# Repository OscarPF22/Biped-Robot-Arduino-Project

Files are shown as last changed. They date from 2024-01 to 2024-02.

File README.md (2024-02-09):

# Biped-Robot-Arduino-Project
This repository contains all the main files involved in the development of the Final degree project in Electronic Systems Engineering from the University of Malaga.
- PCB_ESP32_UnaCara_Galgas: This folder contains all the files from the KiCad project (PCI/PCB development).
- STL Biped Robot: This folder contains all the STL files of the 3D printed parts used to build the robot.
- analog_pid_IMU_esp32_v2: This folder contains the Arduino codes for the stability control (the analog part is commented and not used).
- ik_v14_esp32: This folder contains the Arduino codes for making the robot walk (mainly inverse kinematics).

<p align="center">
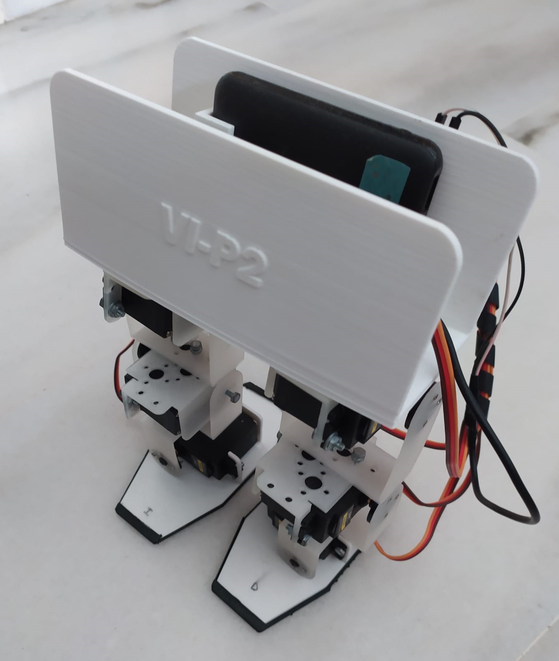
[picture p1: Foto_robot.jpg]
hoto of the final prototype
  
</p>

Walking demo video:

<p align="center">
  <a href="https://www.youtube.com/watch?v=WyaLR0LmY2Y">
    Video de ejemplo
  </a>
</p>

Stabilization demo video:

<p align="center">
  <a href="https://www.youtube.com/watch?v=4yBQPxzZWLo">
    Video de ejemplo
  </a>
</p>

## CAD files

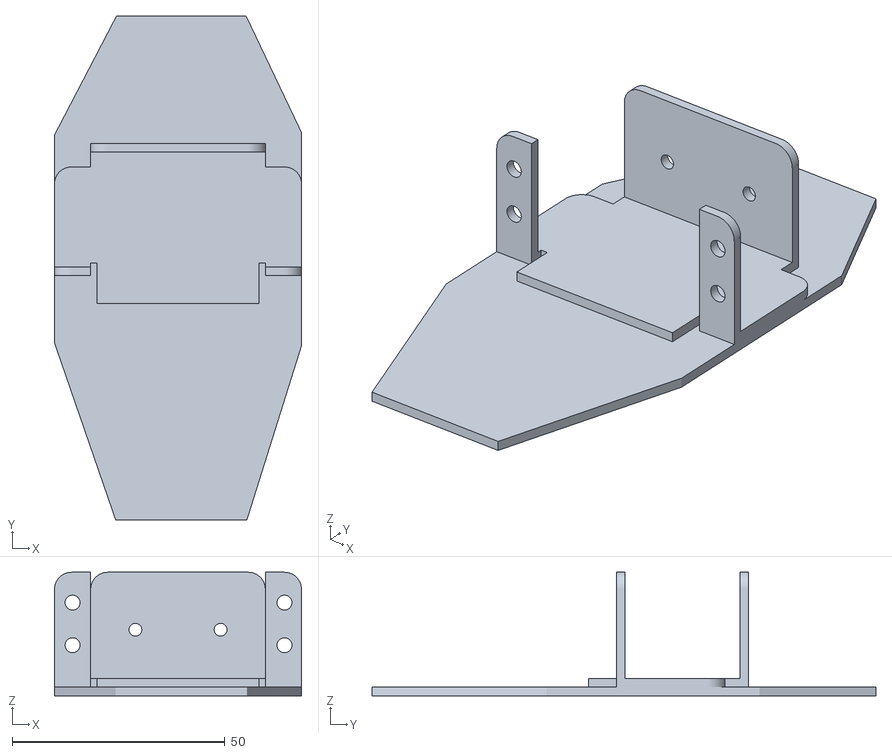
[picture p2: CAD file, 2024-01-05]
STL Biped Robot/mod_pie.stl
58.0 x 118.3 x 29.0

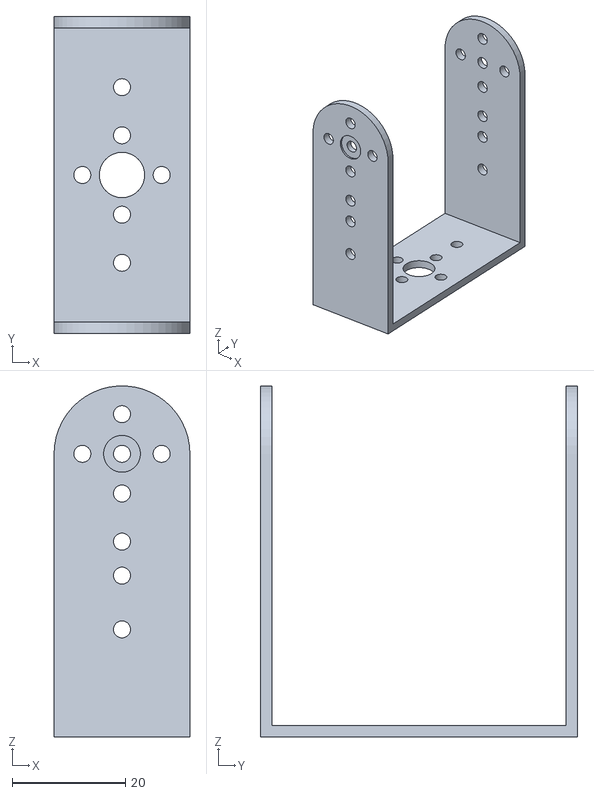
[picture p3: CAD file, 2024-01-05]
STL Biped Robot/Bracket-Long-C.stl
24.0 x 56.0 x 62.0

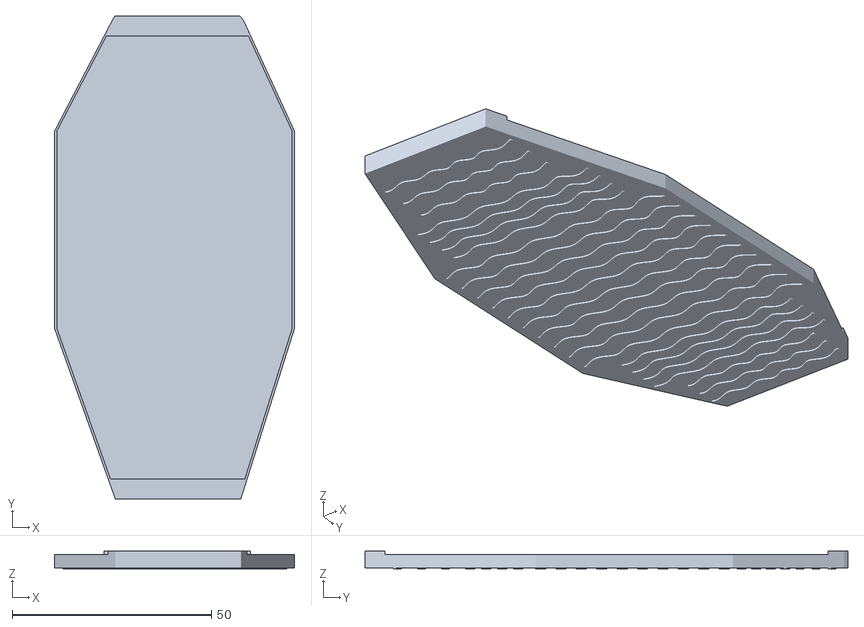
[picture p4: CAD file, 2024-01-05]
STL Biped Robot/Suela_pie_v6.stl
60.2 x 121.1 x 4.50

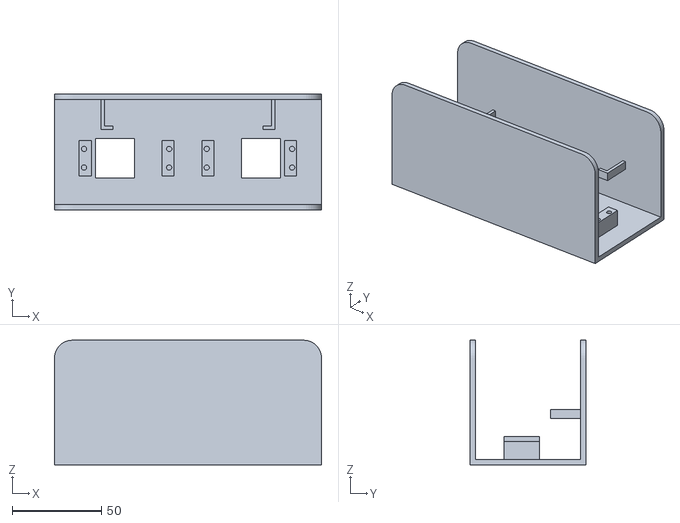
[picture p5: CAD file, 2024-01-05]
STL Biped Robot/cadera_diseño_fin.stl
150.0 x 65.0 x 70.0

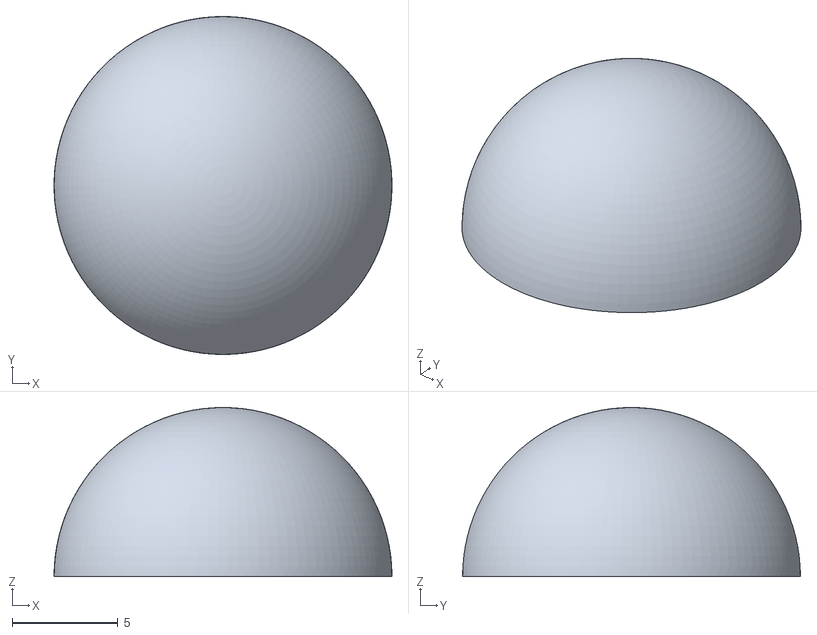
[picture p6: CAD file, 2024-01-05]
STL Biped Robot/semiesfera v1.stl
16.0 x 16.0 x 8.00

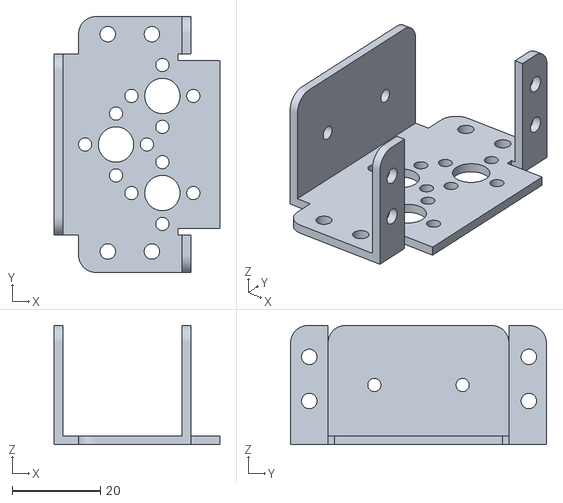
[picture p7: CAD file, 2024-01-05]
STL Biped Robot/Bracket-Multi.stl
37.5 x 58.0 x 27.0

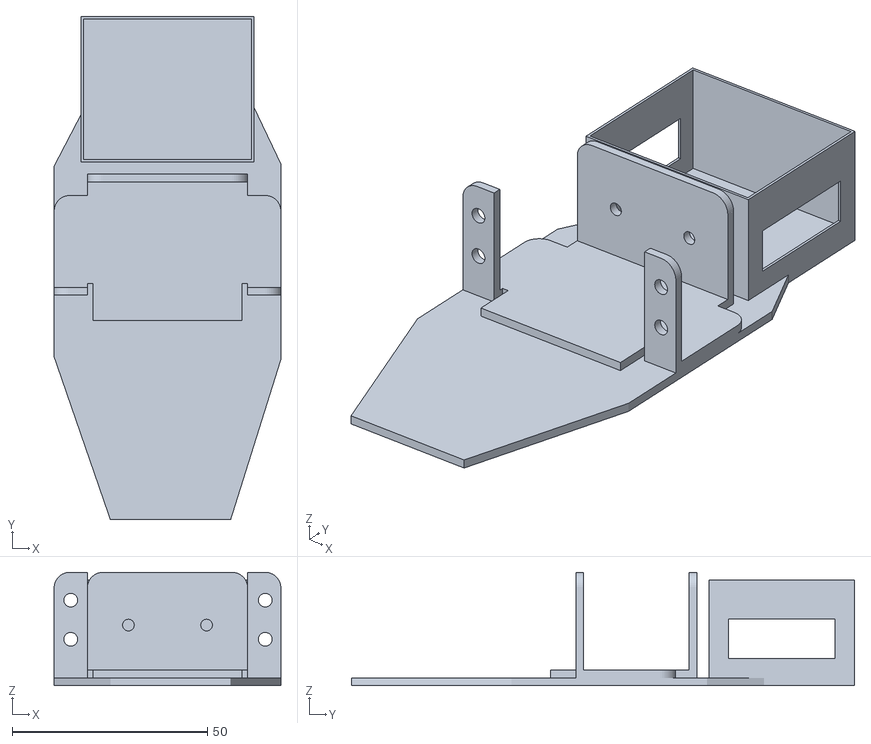
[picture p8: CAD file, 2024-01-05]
STL Biped Robot/mod_pie_placa_v2.stl
58.0 x 128.7 x 29.0

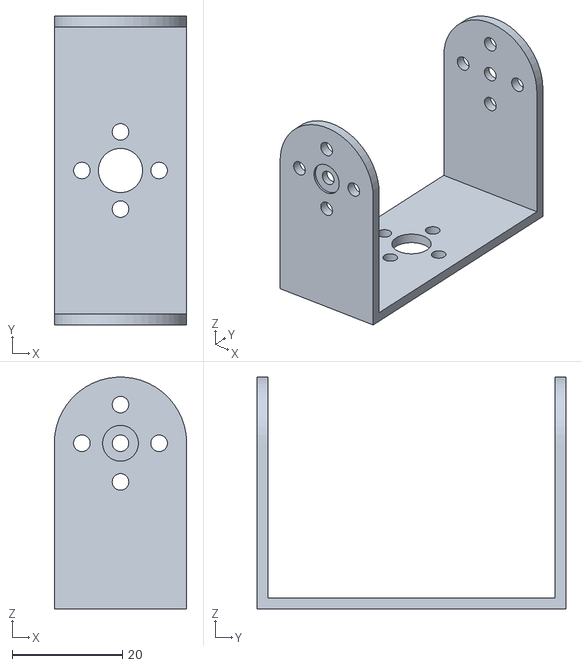
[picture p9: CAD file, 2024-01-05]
STL Biped Robot/Bracket-Reg-C.stl
24.0 x 56.0 x 42.0

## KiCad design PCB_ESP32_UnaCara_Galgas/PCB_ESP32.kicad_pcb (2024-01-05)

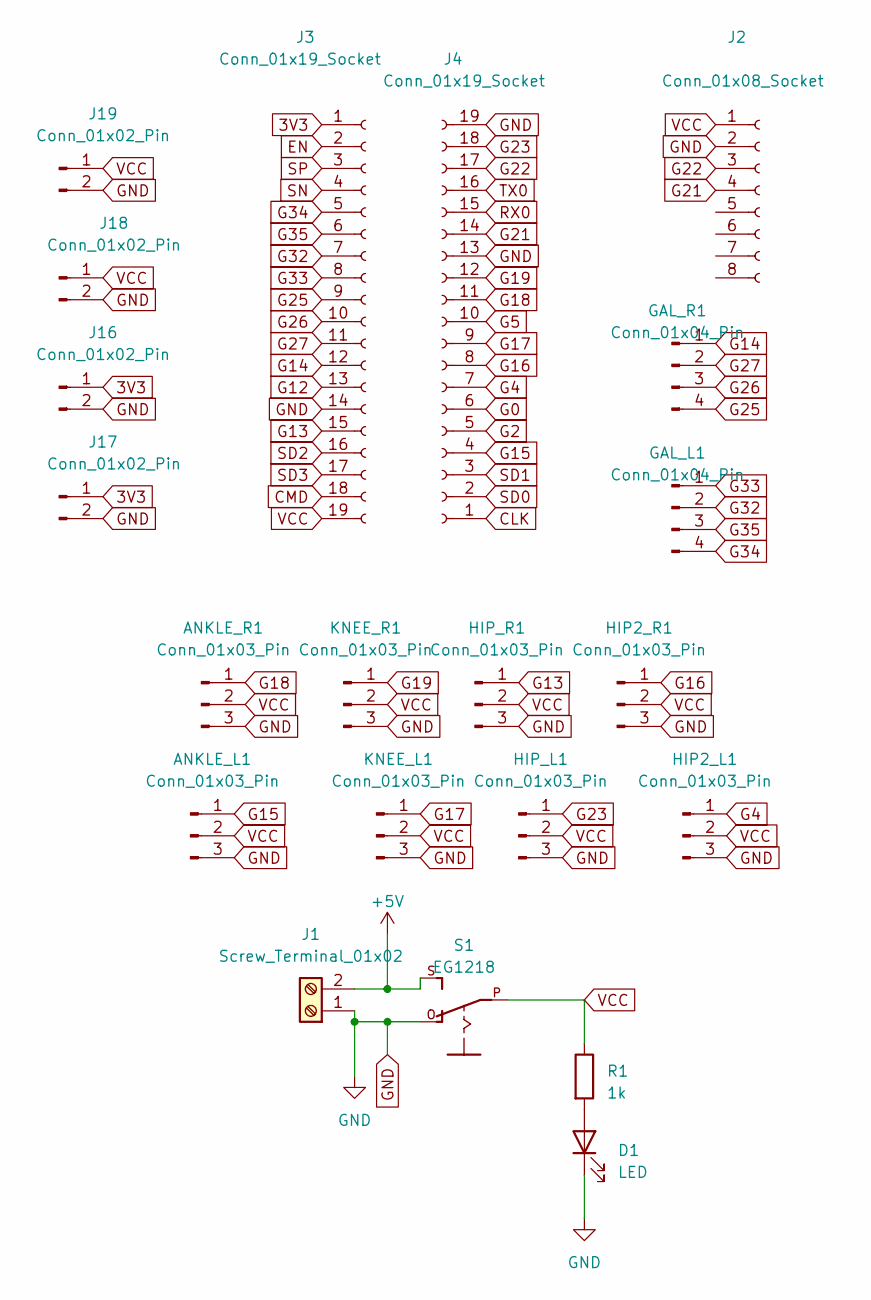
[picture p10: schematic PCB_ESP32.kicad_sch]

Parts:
ANKLE_L1: Conn_01x03_Pin; PinHeader_1x03_P2.54mm_Vertical
ANKLE_R1: Conn_01x03_Pin; PinHeader_1x03_P2.54mm_Vertical
D1: LED; LED_D3.0mm
GAL_L1: Conn_01x04_Pin; PinHeader_1x04_P2.54mm_Vertical
GAL_R1: Conn_01x04_Pin; PinHeader_1x04_P2.54mm_Vertical
HIP2_L1, HIP2_R1: Conn_01x03_Pin; PinHeader_1x03_P2.54mm_Vertical
HIP_L1: Conn_01x03_Pin; PinHeader_1x03_P2.54mm_Vertical
HIP_R1: Conn_01x03_Pin; PinHeader_1x03_P2.54mm_Vertical
J1: Screw_Terminal_01x02; TerminalBlock_Altech_AK300-2_P5.00mm
J2: Conn_01x08_Socket; PinSocket_1x08_P2.54mm_Vertical
J3, J4: Conn_01x19_Socket; PinSocket_1x19_P2.54mm_Vertical
J16, J17, J18, J19: Conn_01x02_Pin; PinHeader_1x02_P2.54mm_Vertical
KNEE_L1: Conn_01x03_Pin; PinHeader_1x03_P2.54mm_Vertical
KNEE_R1: Conn_01x03_Pin; PinHeader_1x03_P2.54mm_Vertical
R1: 1k; R_Axial_DIN0204_L3.6mm_D1.6mm_P5.08mm_Horizontal
S1: EG1218

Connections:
3V3: J3.1, J16.1, J17.1
+5V: J1.2, S1.S
CLK: J4.1
CMD: J3.18
EN: J3.2
G0: J4.6
G2: J4.5
G4: HIP2_L1.1, J4.7
G5: J4.10
G12: J3.13
G13: HIP_R1.1, J3.15
G14: GAL_R1.1, J3.12
G15: ANKLE_L1.1, J4.4
G16: HIP2_R1.1, J4.8
G17: J4.9, KNEE_L1.1
G18: ANKLE_R1.1, J4.11
G19: J4.12, KNEE_R1.1
G21: J2.4, J4.14
G22: J2.3, J4.17
G23: HIP_L1.1, J4.18
G25: GAL_R1.4, J3.9
G26: GAL_R1.3, J3.10
G27: GAL_R1.2, J3.11
G32: GAL_L1.2, J3.7
G33: GAL_L1.1, J3.8
G34: GAL_L1.4, J3.5
G35: GAL_L1.3, J3.6
GND: ANKLE_L1.3, ANKLE_R1.3, D1.1 (K), HIP2_L1.3, HIP2_R1.3, HIP_L1.3, HIP_R1.3, J1.1, J2.2, J3.14, J4.13, J4.19, J16.2, J17.2, J18.2, J19.2, KNEE_L1.3, KNEE_R1.3, S1.O
unnamed: D1.2 (A), R1.2
RX0: J4.15
SD0: J4.2
SD1: J4.3
SD2: J3.16
SD3: J3.17
SN: J3.4
SP: J3.3
TX0: J4.16
VCC: ANKLE_L1.2, ANKLE_R1.2, HIP2_L1.2, HIP2_R1.2, HIP_L1.2, HIP_R1.2, J2.1, J3.19, J18.1, J19.1, KNEE_L1.2, KNEE_R1.2, R1.1, S1.P

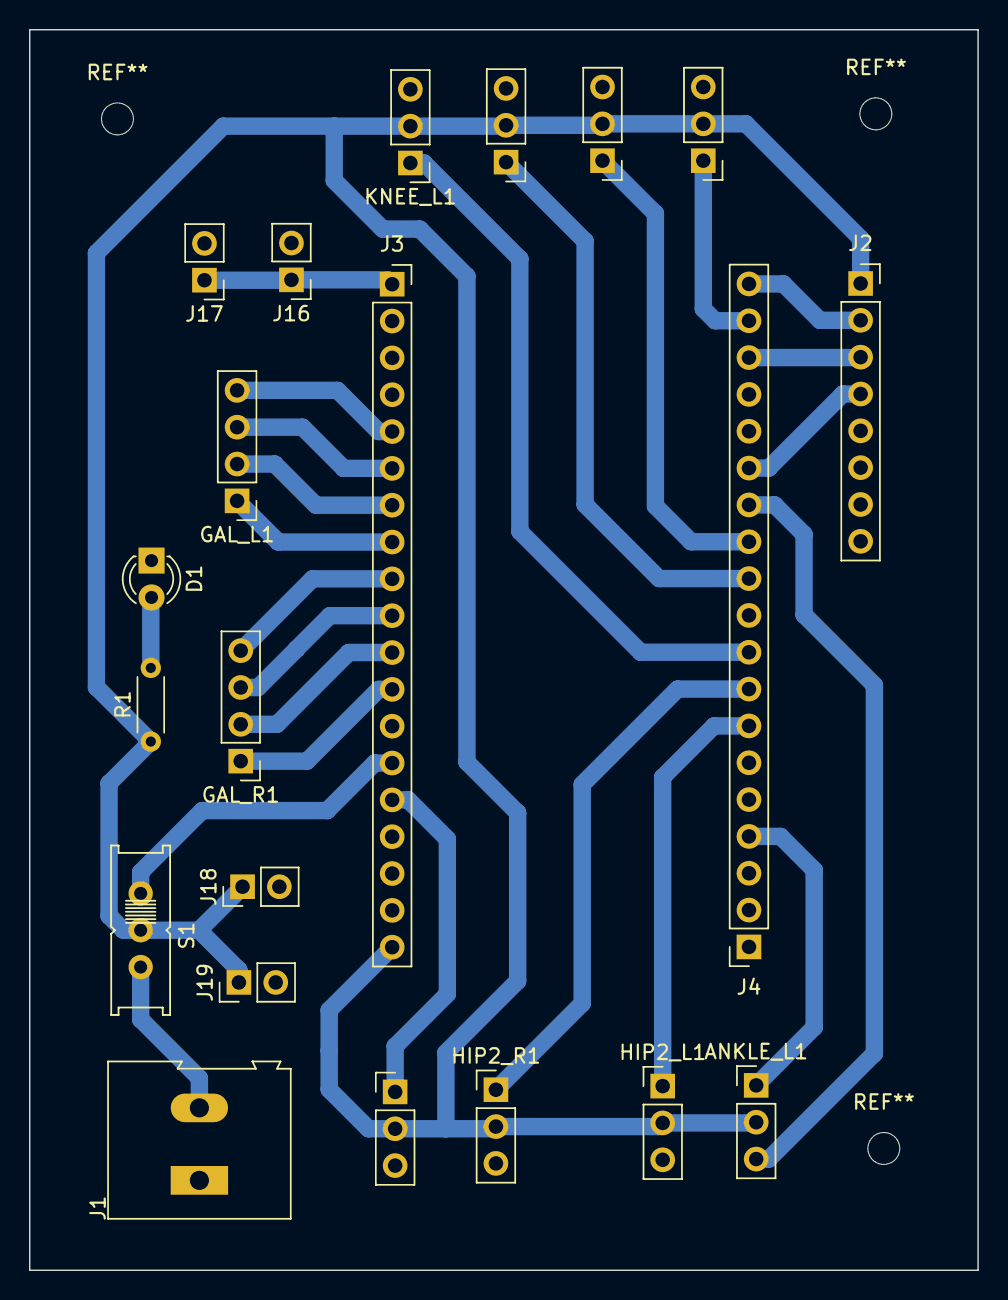
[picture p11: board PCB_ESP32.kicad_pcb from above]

Board: 2 copper layers, 65.4 x 85.5 mm, 21 parts (0 on the bottom side), 23 nets.

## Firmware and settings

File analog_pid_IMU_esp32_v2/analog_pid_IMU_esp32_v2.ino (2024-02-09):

#include "funciones_analog.h"
#include "FuncionesControl.h"
#include "servo_robot.h"
#include "MPU6050.h"

unsigned int galgas[8] = {34, 35, 32, 33, 25, 26, 27, 14}; // 4 primeras izq, 4 ultimas der
Servo IniServo_Array[NUM_SERVOS];

//Para controlar periodo bucle PID:
unsigned long now = 0;
unsigned long period = 0;
unsigned long lastTime = 0;

void setup() 
{
  Serial.begin(115200); //Para depurar
  
  //INICIALIZO CONTROLADOR PID:
  pidControllerTobilloR.SetTuningValues(0.0, 0.8, 0.0, 0.5); //SetPoint, Kp, Ki, Kd //0.0000001
  pidControllerRodillaR.SetTuningValues(0.0, 0.4, 0.0, 0.06); 
  pidControllerTobilloL.SetTuningValues(0.0, 0.8, 0.0, 0.5); 
  pidControllerRodillaL.SetTuningValues(0.0, 0.4, 0.0, 0.06); 

  //INICIALIZO MPU6050:
  if (!mpu.begin()) 
  {
    Serial.println("Failed to find MPU6050 chip");
    while (1) 
    {
      delay(10);
    }
  }
  mpuSetConfig(MPU6050_RANGE_16_G, MPU6050_RANGE_500_DEG, MPU6050_BAND_21_HZ);

  //INICIALIZO SERVOS:
  Servo_Array[RODILLA_R].setPeriodHertz(50); // Standard 50hz servo
  Servo_Array[CADERA_R].setPeriodHertz(50); 
  Servo_Array[TOBILLO_R].setPeriodHertz(50);
  Servo_Array[CADERA2_R].setPeriodHertz(50);
  Servo_Array[RODILLA_L].setPeriodHertz(50);
  Servo_Array[CADERA_L].setPeriodHertz(50);
  Servo_Array[TOBILLO_L].setPeriodHertz(50);
  Servo_Array[CADERA2_L].setPeriodHertz(50);

  //Adjudico pines
  Servo_Array[RODILLA_R].attach(16, 500, 2500); //19
  Servo_Array[CADERA_R].attach(13, 500, 2500);    
  Servo_Array[TOBILLO_R].attach(23, 500, 2500); //18
  Servo_Array[CADERA2_R].attach(17, 500, 2500); 
  Servo_Array[RODILLA_L].attach(19, 500, 2500); //17
  Servo_Array[CADERA_L].attach(18, 500, 2500);  //23  
  Servo_Array[TOBILLO_L].attach(15, 500, 2500); 
  Servo_Array[CADERA2_L].attach(4, 500, 2500);
  
  delay(3000);
  
  RobotInitialize();
  get_MPU_Values();
  
  delay(5000);
}

void loop() 
{
  /*ReadVolt(galgas);
  ReadResist();
  ReadWeight(lt2_resist_right, W_right, GALGAS_R);
  ReadWeight(lt2_resist_left, W_left, GALGAS_L);

  Serial.print(W_left[0]);
  Serial.print("  ");
  Serial.print(W_left[1]);
  Serial.print("  ");
  Serial.print(W_left[2]);
  Serial.print("  ");
  Serial.println(W_left[3]);
  /////
  Serial.print(W_right[0]);
  Serial.print("  ");
  Serial.print(W_right[1]);
  Serial.print("  ");
  Serial.print(W_right[2]);
  Serial.print("  ");
  Serial.println(W_right[3]);
  CalculoCoG();*/

  CorregirPose();
  
  now = millis();
  period = now - lastTime;
  Serial.print("Periodo PID: ");
  Serial.println(period);
  lastTime = now;

}

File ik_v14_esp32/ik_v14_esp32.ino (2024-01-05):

#include "servo_lineal.h"
#include "funciones_paso.h"

Servo IniServo_Array[NUM_SERVOS];
int zancadas = 1;

void setup() 
{
  Serial.begin(115200); //Para depurar
  
  IniServo_Array[RODILLA_R].setPeriodHertz(50); // Standard 50hz servo
  IniServo_Array[CADERA_R].setPeriodHertz(50); 
  IniServo_Array[TOBILLO_R].setPeriodHertz(50);
  IniServo_Array[CADERA2_R].setPeriodHertz(50);
  IniServo_Array[RODILLA_L].setPeriodHertz(50);
  IniServo_Array[CADERA_L].setPeriodHertz(50);
  IniServo_Array[TOBILLO_L].setPeriodHertz(50);
  IniServo_Array[CADERA2_L].setPeriodHertz(50);

  //Adjudico pines
  IniServo_Array[RODILLA_R].attach(16, 500, 2500); //19
  IniServo_Array[CADERA_R].attach(13, 500, 2500);    
  IniServo_Array[TOBILLO_R].attach(23, 500, 2500); //18
  IniServo_Array[CADERA2_R].attach(17, 500, 2500); 
  IniServo_Array[RODILLA_L].attach(19, 500, 2500); //17
  IniServo_Array[CADERA_L].attach(18, 500, 2500);  //23  
  IniServo_Array[TOBILLO_L].attach(15, 500, 2500); 
  IniServo_Array[CADERA2_L].attach(4, 500, 2500);
  
  Servos.SetServoValues(Servo_Nuevos_Valores);
  Servos.SetServoArray(IniServo_Array);
  
  delay(3000);
  
  Servos.RobotInitialize();

  delay(5000);
}


void loop() 
{

  Swinging(); // BALANCEO INICIAL
  Calculate_Step(PASO); // CALCULO LA IK DEL PASO Y LA EJECUTO
  Support(); // APOYO FINAL
  
  Serial.println("FIN PASO");
  
  zancadas++;
  
  // Doy 16 pasos
  if(zancadas == 12)//8
  {
    zancadas = 0;
    while (zancadas <= 4) // giro 5 veces (90º aprox) //4
    {
      Rotation_Right();
      zancadas++;
      Serial.println("giro");
    }
    zancadas = 0; // Reinicio Cuenta y sigo andando
    delay(200);
  }
}

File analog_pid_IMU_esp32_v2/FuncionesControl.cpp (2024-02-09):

#include "FuncionesControl.h"

//Controlador PID
PID_Controller pidControllerTobilloR, pidControllerTobilloL, pidControllerRodillaR, pidControllerRodillaL;
float tobilloL_max = 65, tobilloL_min = 45, servo_range = 10;
float tobilloR_max = 90, tobilloR_min = 70;
float rodillaL_max = 98, rodillaL_min = 78;
float rodillaR_max = 102, rodillaR_min = 82;


void PID_Controller::SetTuningValues(double new_Setpoint, double new_Kp, double new_Ki, double new_Kd)
{
   Setpoint = new_Setpoint;
   kp = new_Kp;
   ki = new_Ki;
   kd = new_Kd;
}

void PID_Controller::Update(double Input)
{
   /*How long since we last calculated*/
   unsigned long now = millis();
   double timeChange = (double)(now - lastTime);
  
   /*Compute all the working error variables*/
   double error = Setpoint - Input;
   errSum += (error * timeChange);
   double dErr = (error - lastErr) / timeChange;
  
   /*Compute PID Output*/
   Output = kp * error + ki * errSum + kd * dErr;
  
   /*Remember some variables for next time*/
   lastErr = error;
   lastTime = now;
}

//Controlador PID
void CorregirPose()
{
  get_MPU_Values(); // leo los valores del MPU y los almaceno
  calculate_tilt_angle(); // traduzco los datos a grados de inclinacion
  
  pidControllerTobilloR.Update(tiltY);
  pidControllerRodillaR.Update(tiltZ);
  pidControllerTobilloL.Update(tiltY);
  pidControllerRodillaL.Update(tiltZ);

  Serial.print("PID TobilloL & RodillaL: ");
  Serial.print(pidControllerTobilloL.Output, 3);
  Serial.print("  //  ");
  Serial.println(pidControllerRodillaL.Output, 3);
  Serial.print("Tobillo R & Rodilla R: ");
  Serial.print(pidControllerTobilloR.Output, 3);
  Serial.print("  //  ");
  Serial.println(pidControllerRodillaR.Output, 3);
  Serial.print("\n"); 

  float set_tobilloR = map(pidControllerTobilloR.Output, (-1*servo_range), servo_range, tobilloR_max, tobilloR_min);
  float set_rodillaR = map(pidControllerRodillaR.Output, (-1*servo_range) , servo_range, rodillaR_min, rodillaR_max);
  float set_tobilloL = map(pidControllerTobilloL.Output, (-1*servo_range), servo_range, tobilloL_max, tobilloL_min);
  float set_rodillaL = map(pidControllerRodillaL.Output, (-1*servo_range) , servo_range, rodillaL_max, rodillaL_min);

  //Comprobación de límites por seguridad:
  set_tobilloL = constrain(set_tobilloL, tobilloL_min, tobilloL_max);
  set_tobilloR = constrain(set_tobilloR, tobilloR_min, tobilloR_max);
  set_rodillaL = constrain(set_rodillaL, rodillaL_min, rodillaL_max);
  set_rodillaR = constrain(set_rodillaR, rodillaR_min, rodillaR_max);
  
  Servo_Array[TOBILLO_L].write(set_tobilloL);
  Servo_Array[TOBILLO_R].write(set_tobilloR);
  delay(100); // sobrecarga de corriente
  Servo_Array[RODILLA_L].write(set_rodillaL);
  Servo_Array[RODILLA_R].write(set_rodillaR);
  
  Serial.print("Tobillo L & Rodilla L: ");
  Serial.print(set_tobilloL, 3);
  Serial.print("  //  ");
  Serial.println(set_rodillaL, 3);
  Serial.print("Tobillo R & Rodilla R: ");
  Serial.print(set_tobilloR, 3);
  Serial.print("  //  ");
  Serial.println(set_rodillaR, 3);
  Serial.print("\n\n");
}

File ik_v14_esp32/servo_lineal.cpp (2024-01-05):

#include "servo_lineal.h"

void ServoLineal::WriteLineal(double Servo_Nuevos_Valores[], double step_time)
{
  const double inc_time = 20000.0; // 50 Hz
  double inc[NUM_SERVOS]; // array que contiene los incrementos de posición en cada ciclo
  
  unsigned long previous; // tiempo previo para calcular cuando se hace el siguiente incremento
  unsigned out = 0; // variable de control para salir del bucle
  char buf[50];

  for(int i = 0; i < NUM_SERVOS; i++) // comparo los valores que tengo que actualizar y calculo sus incrementos
  {
    inc[i] = ((Servo_Nuevos_Valores[i] - Servo_Valores[i])*inc_time)/step_time;

    //Para debugear
    sprintf(buf, "Incremento [%d] vale ... %f", i, inc[i]);
    Serial.println(buf);
    
    if(inc[i] == 0) // si es cero es porque los valores eran igual (se mantienen)
    {
      out++;
    }
  }

  previous = micros(); // calculo tiempo previo al cambio
  
  while( out != NUM_SERVOS )
  {
    for(int i = 0; i < NUM_SERVOS; i++) 
    {
      if(inc[i] != 0)
      {
        Servo_Valores[i] += inc[i]; // actualizo valor
        Servo_Array[i].Servo::write(Servo_Valores[i]); // ejecuto movimiento
        
        if((abs(Servo_Nuevos_Valores[i] - Servo_Valores[i]) < abs(inc[i]))) // si ya he llegado a la posición deseada
        {
          inc[i] = 0; // cancelo el incremento
          
          Servo_Valores[i] = Servo_Nuevos_Valores[i]; // igualo valor (casos en los que no se llega al valor exacto)
          Servo_Array[i].Servo::write(Servo_Valores[i]); // ejecuto movimiento
          
          out++; // aumento la cuenta de salida
        }

        //Para debugear
        sprintf(buf, "Servo %d a .... %f, con inc %f", i,  Servo_Valores[i], inc[i]);
        Serial.println(buf);
      }
    }
    while( micros() < (previous + inc_time) ) // espera activa
    {
    }
    
    previous = micros();
  }
}

void ServoLineal::SetServoValues(double Servo_Nuevos_Valores[])
{
  for(int i = 0; i < NUM_SERVOS; i++)
  {
     Servo_Valores[i] = Servo_Nuevos_Valores[i];
  }
  Serial.println("Valores de servo asignados...");
}

void ServoLineal::SetServoArray(Servo MyServo_Array[])
{
  for(int i = 0; i < NUM_SERVOS; i++)
  {
     Servo_Array[i] = MyServo_Array[i];
  }
  Serial.println("Array de servo asignado...");
}
void ServoLineal::RobotInitialize()
{
  char buf[60];
  for(int i = 0; i < (NUM_SERVOS/2); i++)
  {
     Servo_Array[i].write(Servo_Valores[i]);
     Servo_Array[i+(NUM_SERVOS/2)].write(Servo_Valores[i+(NUM_SERVOS/2)]);

     //Para debugear
     sprintf(buf, "Servos %d y %d inicializados a .... %f y %f",  i,  (i+(NUM_SERVOS/2)), Servo_Valores[i], Servo_Valores[i+(NUM_SERVOS/2)]);
     Serial.println(buf);
     
     delay(100); // delay de 100 ms entre cada movimiento de motor para no demandar excesiva corriente
  }
}

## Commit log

2024-01-05 upload missing STL file
    [mod_pie.stl]
2024-02-09 upload pid controller
